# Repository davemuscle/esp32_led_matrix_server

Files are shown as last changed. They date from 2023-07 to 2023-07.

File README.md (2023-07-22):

# ESP32 LED Matrix Fileserver

Upload images, gifs, and text files for display on an LED matrix!

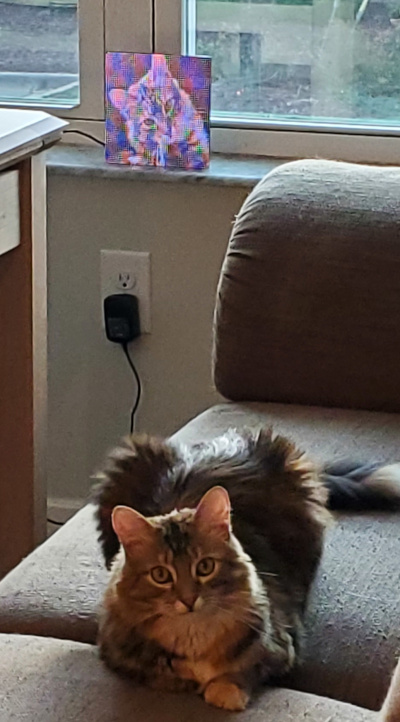
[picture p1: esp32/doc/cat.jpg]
|  |
| :--: |
| *Cat* |

The board consists of an ESP32 microcontroller and an SD card.
The SD card can be accessed remotely through a web browser, after some setup is complete.

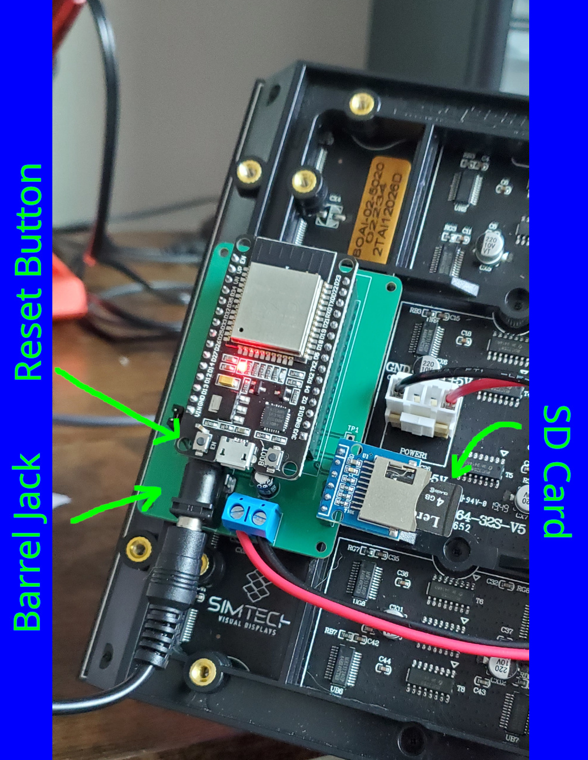
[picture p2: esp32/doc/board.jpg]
|  |
| :--: |
| *ESP32 Board* |

## Setup Steps

### 1. Network Credentials

Remove the microSD card from the ESP32 board and insert it into a disk reader on your PC. 
Create a file called "credentials.h", or open it if it already exists.

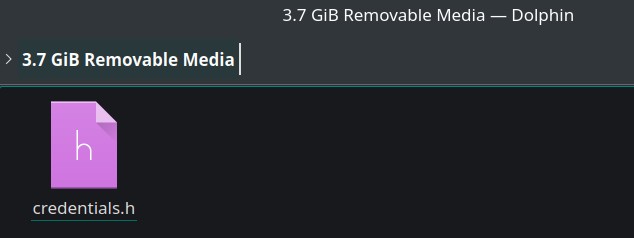
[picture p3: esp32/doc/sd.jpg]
|  |
| :--: |
| *Mounted SD card* |

Open the file in a text editor and input your network SSID and password on consecutive lines.

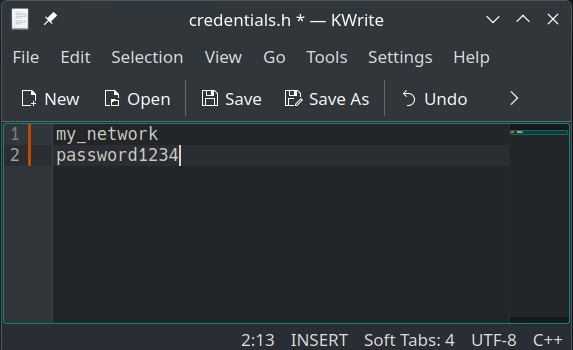
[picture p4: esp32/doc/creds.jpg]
|  |
| :--: |
| *Credentials* |

Place the SD card back into the ESP32 board.

### 2. Power

Plug the onboard barrel-jack into a 5V DC power supply.
Anything at or above 5V-1A will work:

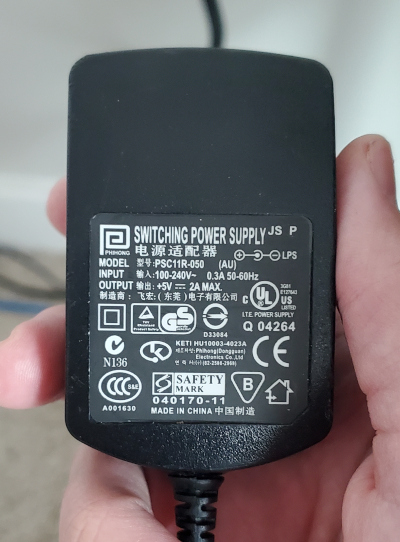
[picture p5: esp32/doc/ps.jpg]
|  |
| :--: |
| *Example Power Supply* |

### 3. Webserver

After plugging in the board with the network credentials loaded, the ESP32 will connect to your home network.
The IP address of the ESP32 will be displayed on the LED matrix, like this:

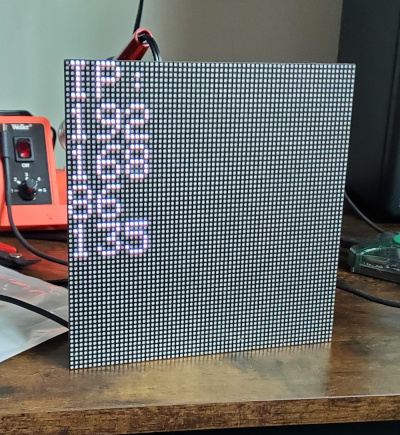
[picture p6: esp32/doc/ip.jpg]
|  |
| :--: |
| *Displayed IP* |

Note:
If the IP address is displayed is shifted and blurry, reapply power to the board or press the reset button.

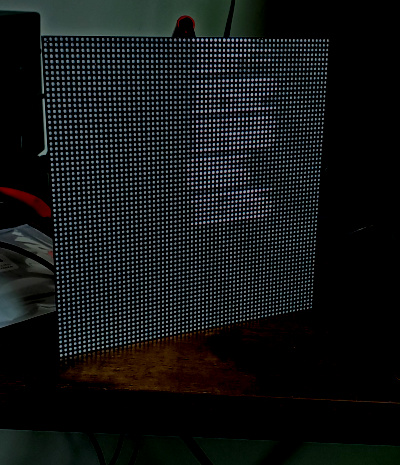
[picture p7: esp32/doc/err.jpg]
|  |
| :--: |
| *Screen malfunction, reset!* |

In your web broswer, enter the IP address, eg:
```
http://192.168.86.135
```

You may be able to connect using mDNS, instead of the IP address: 
```
esp32.local
```

If that doesn't work, you need install an mDNS service like Bonjour (Windows)

### 4. Upload Images

If the previous steps worked, you'll be able to access the fileserver:

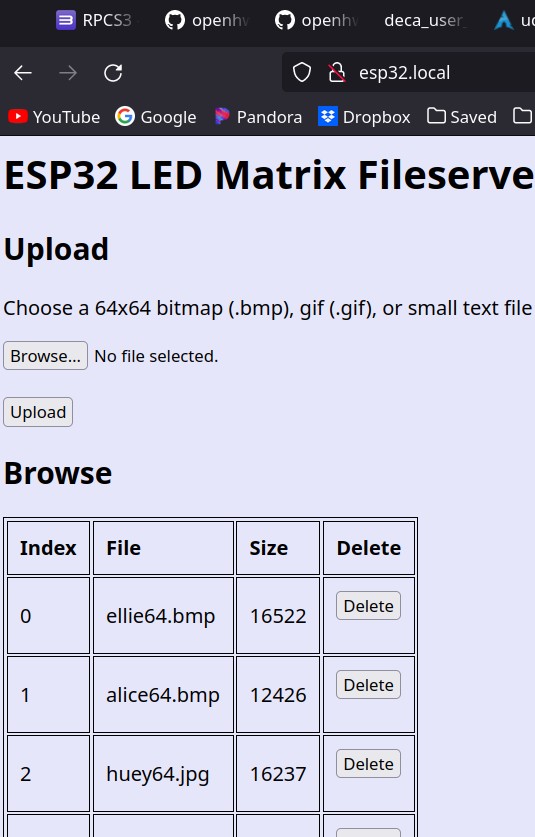
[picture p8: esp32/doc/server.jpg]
|  |
| :--: |
| *File Server* |

The images/gifs you upload must be 64x64 in size, and text files will wrap around as needed.
The accepted file formats are:
* .txt
* .bmp
* .gif

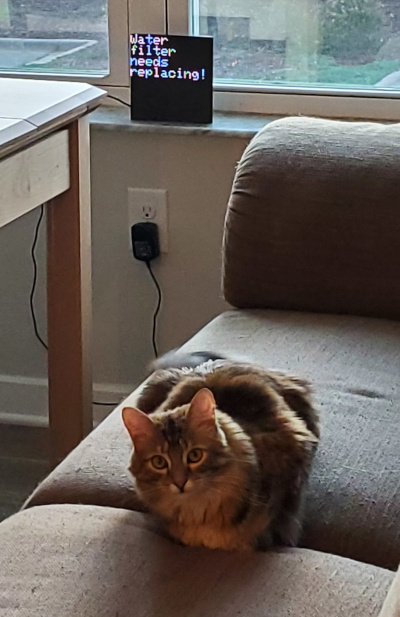
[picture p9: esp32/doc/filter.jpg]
|  |
| :--: |
| *Telepathy* |

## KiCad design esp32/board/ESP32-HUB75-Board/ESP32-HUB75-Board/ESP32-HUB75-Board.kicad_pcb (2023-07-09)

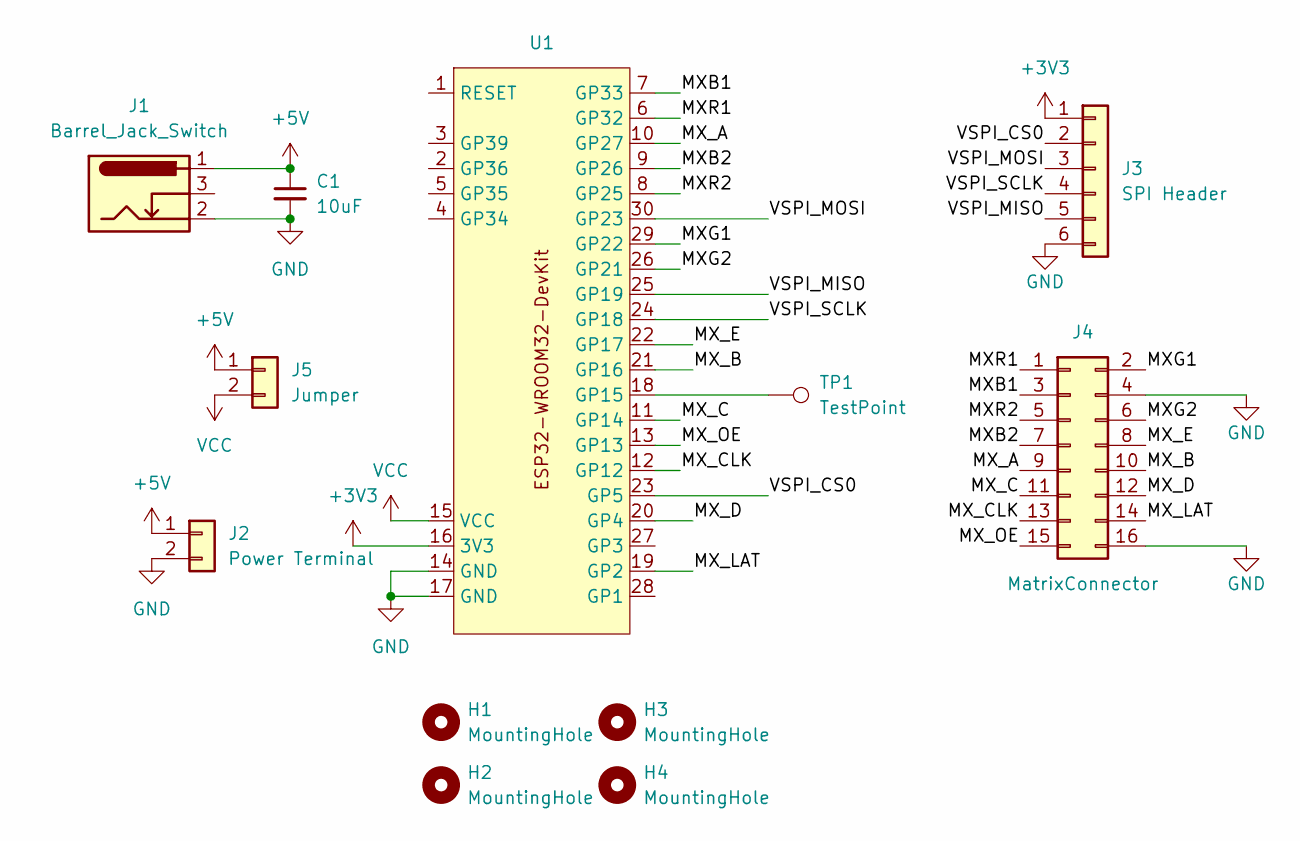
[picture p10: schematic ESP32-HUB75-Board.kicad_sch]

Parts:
C1: 10uF; CP_Radial_Tantal_D5.0mm_P2.50mm
H1, H2, H3, H4: MountingHole; MountingHole_2.2mm_M2
J1: Barrel_Jack_Switch; BarrelJack_GCT_DCJ200-10-A_Horizontal
J2: Power Terminal; TerminalBlock_bornier-2_P5.08mm
J3: SPI Header; PinHeader_1x06_P2.54mm_Vertical
J4: MatrixConnector; PinHeader_2x08_P2.54mm_Vertical
J5: Jumper; PinHeader_1x02_P2.54mm_Vertical
TP1: TestPoint; PinHeader_1x01_P2.54mm_Vertical
U1: ESP32-WROOM32-DevKit

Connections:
+3V3: J3.1, U1.16 (3V3)
+5V: C1.1, J1.1, J2.1, J5.1
/MXB1: J4.3, U1.7 (GP33)
/MXB2: J4.7, U1.9 (GP26)
/MXG1: J4.2, U1.29 (GP22)
/MXG2: J4.6, U1.26 (GP21)
/MXR1: J4.1, U1.6 (GP32)
/MXR2: J4.5, U1.8 (GP25)
/MX_A: J4.9, U1.10 (GP27)
/MX_B: J4.10, U1.21 (GP16)
/MX_C: J4.11, U1.11 (GP14)
/MX_CLK: J4.13, U1.12 (GP12)
/MX_D: J4.12, U1.20 (GP4)
/MX_E: J4.8, U1.22 (GP17)
/MX_LAT: J4.14, U1.19 (GP2)
/MX_OE: J4.15, U1.13 (GP13)
/VSPI_CS0: J3.2, U1.23 (GP5)
/VSPI_MISO: J3.5, U1.25 (GP19)
/VSPI_MOSI: J3.3, U1.30 (GP23)
/VSPI_SCLK: J3.4, U1.24 (GP18)
GND: C1.2, J1.2, J2.2, J3.6, J4.4, J4.16, U1.14 (GND), U1.17 (GND)
unnamed: TP1.1, U1.18 (GP15)
VCC: J5.2, U1.15 (VCC)

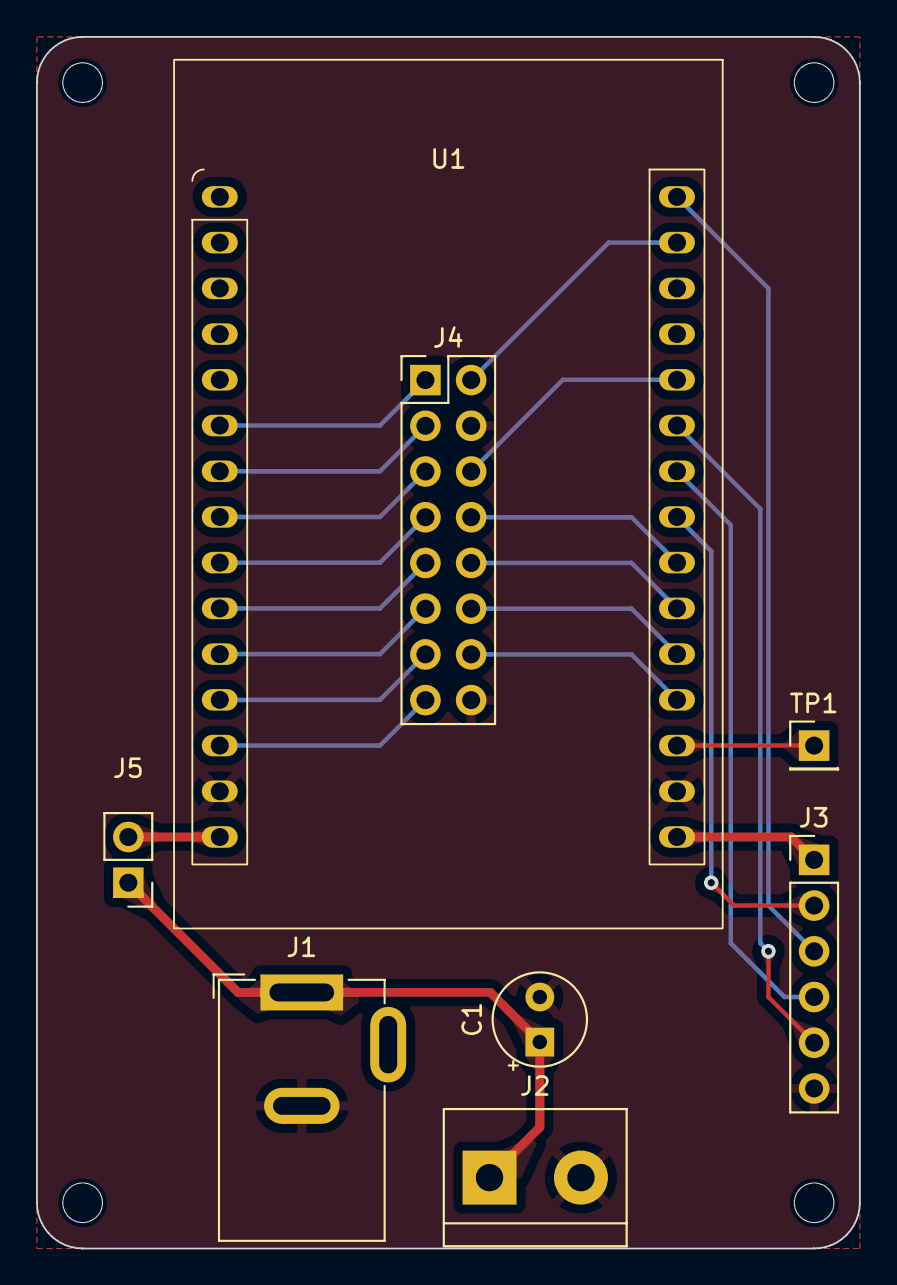
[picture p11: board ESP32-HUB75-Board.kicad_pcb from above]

Board: 2 copper layers, 45.7 x 67.3 mm, 12 parts (0 on the bottom side), 23 nets.

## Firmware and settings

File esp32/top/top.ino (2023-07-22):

#include "top.h"


AnimatedGIF gif;

HUB75_I2S_CFG::i2s_pins _pins = {LM_R1, LM_B1, LM_G1, LM_R2, LM_B2, LM_G2, LM_A, LM_B, LM_C, LM_D, LM_E, LM_LAT, LM_OE, LM_CLK};
MatrixPanel_I2S_DMA *ledmatrix = nullptr;

TaskHandle_t task_server_handle;

void setup() {

    // Serial
    Serial.begin(115200);
    while (!Serial);

    // Debugging power-up display issues:
    pinMode(LM_CLK, OUTPUT);
    pinMode(LM_LAT, OUTPUT);
    pinMode(LM_OE, OUTPUT);
    digitalWrite(LM_CLK, 0);
    digitalWrite(LM_LAT, 0);
    digitalWrite(LM_OE,  1);
    delay(100);
    for(int i = 0; i < DISPLAY_HEIGHT; i++) {
        for(int j = 0; j < DISPLAY_WIDTH; j++){
            digitalWrite(LM_CLK, 1);
            delay(1);
            digitalWrite(LM_CLK, 0);
            delay(1);
        }
        digitalWrite(LM_LAT, 1);
        delay(10);
        digitalWrite(LM_LAT, 0);
        delay(10);
    }

    // LED Matrix
    HUB75_I2S_CFG mxconfig (DISPLAY_HEIGHT, DISPLAY_WIDTH, 1, _pins);
    mxconfig.double_buff = true;
    //mxconfig.clkphase = false;
    ledmatrix = new MatrixPanel_I2S_DMA(mxconfig);
    ledmatrix->begin();
    ledmatrix->setBrightness8(20);
    ledmatrix->setTextColor(ledmatrix->color444(15,15,15));
    ledmatrix->setTextSize(1);
    ledmatrix->setTextWrap(true);

    // File System
    if (!SD.begin(5)) {
        String err = "SD card error!";
        ledmatrix->setCursor(0,0);
        ledmatrix->clearScreen();
        ledmatrix->println(err);
        ledmatrix->flipDMABuffer();
        Serial.println(err);
        return;
    }

    // Read the SSID and password
    String ssid, pass;
    File cred_h = SD.open("/credentials.h");
    if (!cred_h) {
        String err = "No credentials!";
        ledmatrix->setCursor(0,0);
        ledmatrix->clearScreen();
        ledmatrix->println(err);
        ledmatrix->flipDMABuffer();
        Serial.println(err);
        return;
    } else {
        Serial.println("Reading credentials");
        ssid = cred_h.readStringUntil('\n');
        pass = cred_h.readStringUntil('\n');
        ssid.trim();
        pass.trim();
        Serial.println("Network SSID: " + ssid);
        Serial.println("Network pass: " + pass);
    }

    // Wifi
    WiFi.mode(WIFI_STA);
    WiFi.begin(ssid.c_str(), pass.c_str());
    if (WiFi.waitForConnectResult() != WL_CONNECTED) {
        Serial.printf("STA: Failed!\n");
    }
    String ip_line = "IP:\n" + WiFi.localIP().toString();
    Serial.println(ip_line);
    ip_line.replace('.', '.\n');
    ledmatrix->setCursor(0,0);
    ledmatrix->clearScreen();
    ledmatrix->println(ip_line);
    ledmatrix->flipDMABuffer();
    if (WiFi.scanComplete() == -2) WiFi.scanNetworks(true);

    // MDNS
    if(MDNS.begin("esp32")){
        Serial.println("mDNS set to esp32.local");
    }

    // add delay for IP display
    delay(1000);

    // Index File
    init_index();

    // Webserver
    setup_webserver();

    gif.begin(LITTLE_ENDIAN_PIXELS);

    xTaskCreatePinnedToCore(
        task_server,
        "task_server",
        10000,
        NULL,
        1,
        &task_server_handle,
        0
    );

    // Add MDNS service
    MDNS.addService("http", "tcp", 80);

}

void task_server (void *pvParameters){
    Serial.print("Server task running on core ");
    Serial.println(xPortGetCoreID());
    while(1){
        webserver.handleClient();
        delay(1);
    }
}

bool restart = true;
int total_gif_time;
index_t item;

void loop() {

    int flag;
    String name;
    File file;

    fsmutex.lock();
    while(!delete_queue.empty()){
        String path = "/" + delete_queue.back();
        Serial.println("Attempting to remove: " + path);
        if(SD.exists(path.c_str())){
            SD.remove(path.c_str());
        }
        delete_queue.pop_back();
    }
    flag = traverse_index(&item, restart, true);
    fsmutex.unlock();

    restart = false;
    
    if(flag == -1) {
        restart = true;
        delay(5000);
        return;
    }

    name = "/" + String((const char *)item.name);

    if(name.endsWith(".txt")){
        Serial.println("Displaying text from file: " + name);
        file = SD.open(name);
        if(file) {
            ledmatrix->setCursor(0,0);
            ledmatrix->clearScreen();
            while(file.available()){
                ledmatrix->println(file.readStringUntil('\n'));
            }
            ledmatrix->flipDMABuffer();
            file.close();
        } else {
            Serial.println("Failed to open!");
        }
        delay(BMP_MS);
    } else if(name.endsWith(".bmp")){
        Serial.println("Displaying image from file: " + name);
        memset(img_buff, 0, IMG_BUFF_SIZE);
        if((name.endsWith(".bmp") && get_bmp(name))){
            for(int j = 0; j < DISPLAY_HEIGHT; j++) {
                for(int i = 0; i < DISPLAY_WIDTH; i++) {
                    ledmatrix->drawPixel(i,j, img_buff[j][i]);
                }
            }
            ledmatrix->flipDMABuffer();
            delay(BMP_MS);
        } else {
            Serial.println("Failed to open!");
        }
    } else if(name.endsWith(".gif")){
        Serial.println("Displaying gif from file: " + name);
        total_gif_time = 0;
        memset(img_buff, 0, IMG_BUFF_SIZE);
        for(int i = 0; i < GIF_LOOPS; i++){
            if(gif.open(name.c_str(), GIFOpenFile, GIFCloseFile, GIFReadFile, GIFSeekFile, GIFDraw)){
                gif_vx = 0;
                gif_vy = 0;
                if(gif.getCanvasWidth() < DISPLAY_WIDTH){
                    gif_vx = (DISPLAY_WIDTH - gif.getCanvasWidth()) >> 1;
                }
                if(gif.getCanvasHeight() < DISPLAY_HEIGHT){
                    gif_vy = (DISPLAY_HEIGHT - gif.getCanvasHeight()) >> 1;
                }
                int fd = 0;
                while(gif.playFrame(true,&fd)){
                    for(int j = 0; j < DISPLAY_HEIGHT; j++) {
                        for(int i = 0; i < DISPLAY_WIDTH; i++) {
                            ledmatrix->drawPixel(i,j, img_buff[j][i]);
                        }
                    }
                    ledmatrix->flipDMABuffer();
                    total_gif_time += fd;
                    if(total_gif_time >= GIF_MS) break;
                }
                gif.close();
            } else {
                Serial.println("Failed to open!");
                break;
            }
            if(total_gif_time >= GIF_MS) break;
        }
    }
}

// TODO:
/*
Implement move up/down feature for webserver
*/

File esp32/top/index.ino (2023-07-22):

const index_t INDEX_Z;
const uint32_t INDEX_SIZE = sizeof(INDEX_Z);

volatile uint32_t base_idx = 0;

void init_index (){
    File f;

    Serial.println("Initializing index file");
    if(!SD.exists(INDEX_FILE)){
        Serial.println("Creating default index file");
        File f = SD.open(INDEX_FILE, "w");
        index_t item;
        for(int i = 0; i < INDEX_ENTRIES; i++){
            item = INDEX_Z;
            item.idx = i;
            item.base = (i == base_idx) ? true : false;
            f.seek(i*INDEX_SIZE);
            f.write((uint8_t *)&item, INDEX_SIZE);
        }
        f.close();
    }

    index_t item;

    Serial.println("DEBUG: printing all indexes:");
    for(int i = 0; i < INDEX_ENTRIES; i++){
        read_index(&item, i);
        print_index(&item);
    }

    Serial.println("Finding base index");
    for(int i = 0; i < INDEX_ENTRIES; i++){
        if((read_index(&item, i) >= 0) && item.valid && item.base){
            base_idx = item.idx;
            break;
        }
    }
    Serial.println("Got base index: " + String(base_idx));

    Serial.println("Removing files from the index if they don't exist on the SD card");
    for(int i = 0; i < INDEX_ENTRIES; i++){
        if(read_index(&item, i) >= 0 && item.valid && !SD.exists("/" + String((const char *)item.name))){
            item.valid = false;
            write_index(&item, i);
        }
    }

    Serial.println("Adding images to the index that are present on the SD card but missing from the index");
    File root = SD.open("/");
    if (root) {
        index_t dummy;
        root.rewindDirectory();
        File file = root.openNextFile();
        while(file){
            String name = String(file.name());
            Serial.println("Checking on SD card file: " + name);
            if(name.endsWith(".gif") || name.endsWith(".txt") || name.endsWith(".bmp")){
                if(find_index(file.name(), &dummy) == -1){
                    add_index(file.name(), file.size());
                }
            }
            file = root.openNextFile();
        }
        root.close();
    } else {
        Serial.println("Error, couldn't open root directory");
    }

    Serial.println("Done initializing index file");
}

int write_index (index_t *item, uint32_t idx){
    // append is not what you want here, reference cplusplus.com
    File f = SD.open(INDEX_FILE, "r+");
    if(f && idx < INDEX_ENTRIES){
        item->idx = idx;
        f.seek(idx * INDEX_SIZE);
        f.write((uint8_t *)item, INDEX_SIZE);
        f.close();
        //Serial.println("Wrote to index: " + String(idx));
        return 0;
    } else {
        Serial.println("Error writing to index: " + String(idx));
        return -1;
    }
}

int read_index(index_t *item, uint32_t idx){
    File f = SD.open(INDEX_FILE, "r");
    if(f && idx < INDEX_ENTRIES){
        f.seek(idx * INDEX_SIZE);
        f.read((uint8_t *)item, INDEX_SIZE);
        f.close();
        //Serial.println("Read from index: " + String(idx));
        return 0;
    } else {
        Serial.println("Error reading from index: " + String(idx));
        return -1;
    }
}

int find_index (const char *name, index_t *item) {
    File f = SD.open(INDEX_FILE, "r");
    if(f){
        for(int idx = 0; idx < INDEX_ENTRIES; idx++){
            f.seek(idx * INDEX_SIZE);
            f.read((uint8_t *)item, INDEX_SIZE);
            if(item->valid && !strcmp(name, (const char *)item->name)){
                f.close();
                return idx;
            }
        }
        f.close();
        return -1;
    } else {
        Serial.println("Error finding index name: " + String(name));
        return -1;
    }
}

int add_index (const char *name, uint32_t size){

    uint32_t this_idx = base_idx;
    index_t item;

    Serial.println("Attempting to add index: " + String(name) + ", size: " + String(size));

    for(int i = 0; i < INDEX_ENTRIES; i++){
        read_index(&item, this_idx);
        if(!item.valid) break;
        this_idx = (this_idx + 1) & (INDEX_ENTRIES-1); 
        if(i == INDEX_ENTRIES-1){
            Serial.println("Error finding free space for new addition");
            return -1;
        }
    }

    /*
        Point the base backward to the new item
        Point the last item forward to the new item
        Point the new item forward to the base and backward to the last item
    */

    int flag = 0;

    read_index(&item, base_idx);
    uint32_t old_prev = item.prev;
    item.prev = this_idx;
    write_index(&item, base_idx);
    print_index(&item);

    read_index(&item, old_prev);
    item.next = this_idx;
    write_index(&item, old_prev);
    print_index(&item);

    item.valid = true;
    item.base = (this_idx == base_idx) ? true : false;
    item.size = size;
    item.prev = old_prev;
    item.next = base_idx;
    strcpy((char *)item.name, name);
    write_index(&item, this_idx);
    print_index(&item);

    return 0;
}


int delete_index (const char *name){
    Serial.println("Attempting to delete index: " + String(name));

    index_t item;
    uint32_t prev, next;

    int this_idx = find_index(name, &item);
    if(this_idx < 0){
        Serial.println("Error attempting to delete index as it's already missing");
        return -1;
    }

    /*
        Connect the next and prev indexes of the deleted item
    */

    next = item.next;
    prev = item.prev;

    memcpy(&item, &INDEX_Z, INDEX_SIZE);
    write_index(&item, this_idx);

    read_index(&item, prev);
    item.next = next;
    write_index(&item, prev);

    read_index(&item, next);
    item.prev = prev;
    if(this_idx == base_idx){
        base_idx = next;
        item.base = 1;
    }
    write_index(&item, next);

    return 0;
}

int traverse_index (index_t *item, bool restart, bool forward){
    uint32_t fut;
    fut = restart ? base_idx : forward ? item->next : item->prev;
    //Serial.println("Traversing to: " + String(fut));
    if(read_index(item, fut) < 0){
        Serial.println("Error reading next item while traversing index: " + String(fut));
        return -1;
    }
    if(!item->valid){
        return -1;
    } else if ((forward ? item->next : item->prev) == base_idx){
        return 1;
    } else {
        return 0;
    }
}

void print_index (index_t *item){
    Serial.printf("  valid = %d, base = %d, idx = %d, prev = %d, next = %d, name=%s, size %d\n\r", item->valid, item->base, item->idx, item->prev, item->next, String((const char *)item->name), item->size);
}

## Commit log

2023-07-09 Baseline ESP32
    [ESP32-HUB75-Board-B_Cu.gbr, ESP32-HUB75-Board-B_Mask.gbr, ESP32-HUB75-Board-B_Paste.gbr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]
2023-07-09 Add fuse to makefile
